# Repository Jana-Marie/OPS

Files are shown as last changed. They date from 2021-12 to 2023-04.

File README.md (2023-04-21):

# OPS

OPS is a matchbox sized 65W CC/CV lab power supply. It is controlled by SCPI and powered by USB-PD.

**Please Note that this project is not yet fully tested.**

<table>
  <tbody>
    <tr>
      <td colspan="2">
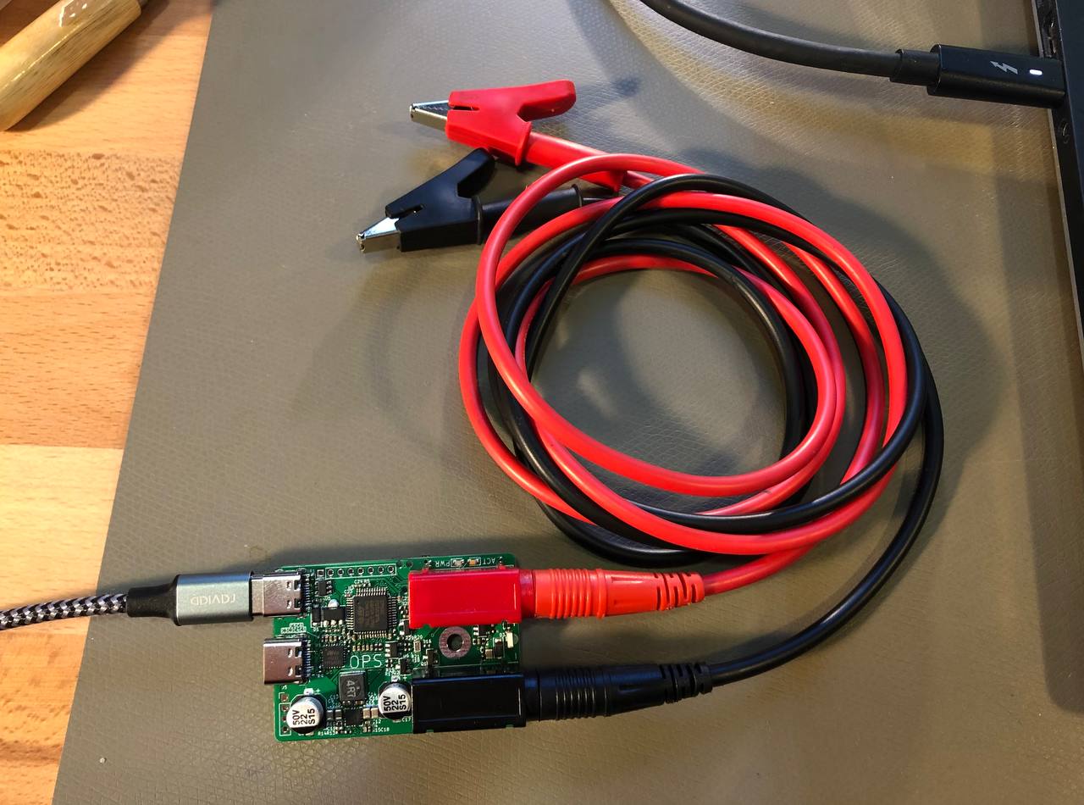
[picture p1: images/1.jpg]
        
      </td>
    </tr>
    <tr>
      <td>
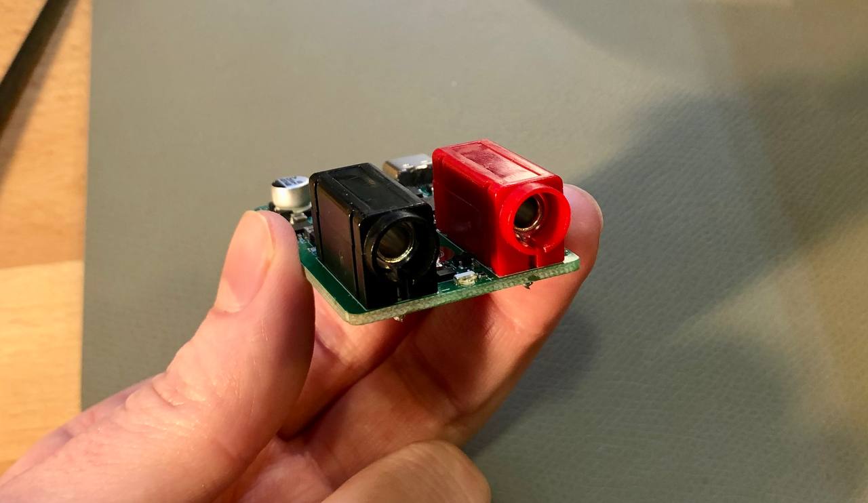
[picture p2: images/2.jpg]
        
      </td>
      <td>
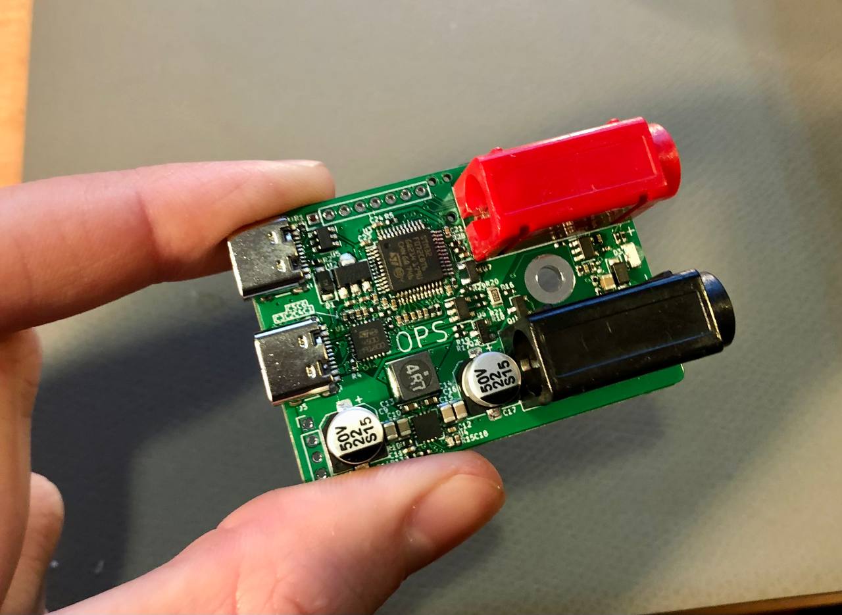
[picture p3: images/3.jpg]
        
      </td>
    </tr>
    <tr>
      <td colspan="2">
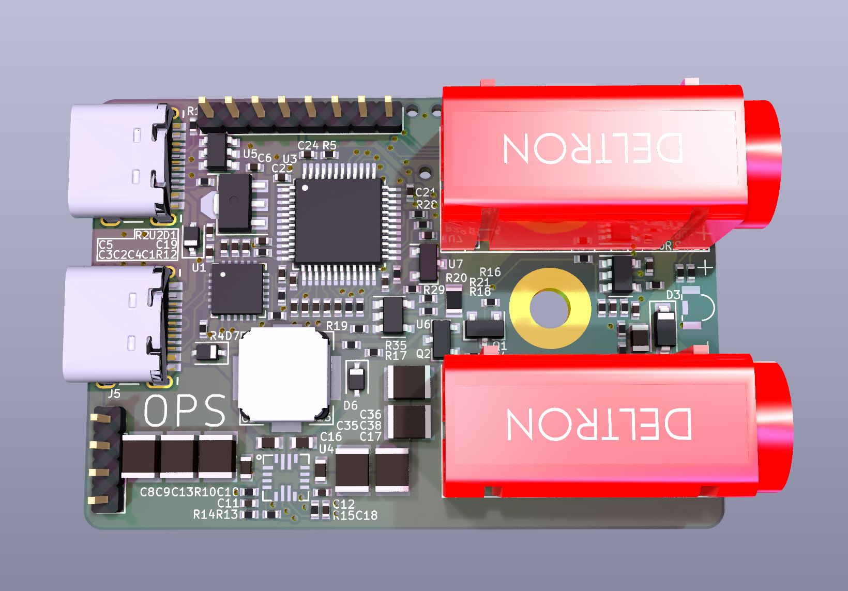
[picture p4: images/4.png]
        
      </td>
    </tr>
    <tr>
      <td>
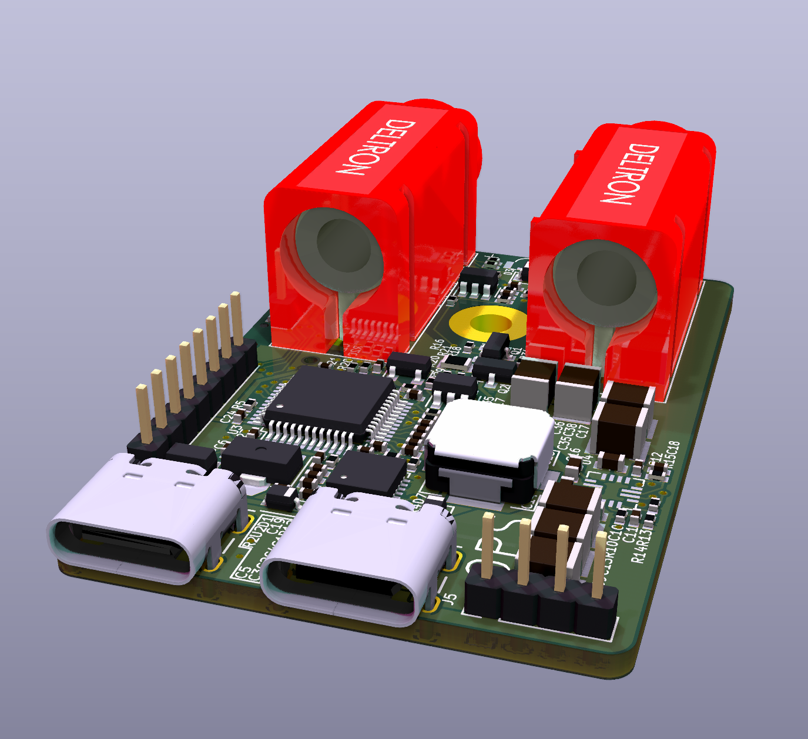
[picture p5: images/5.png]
        
      </td>
      <td>
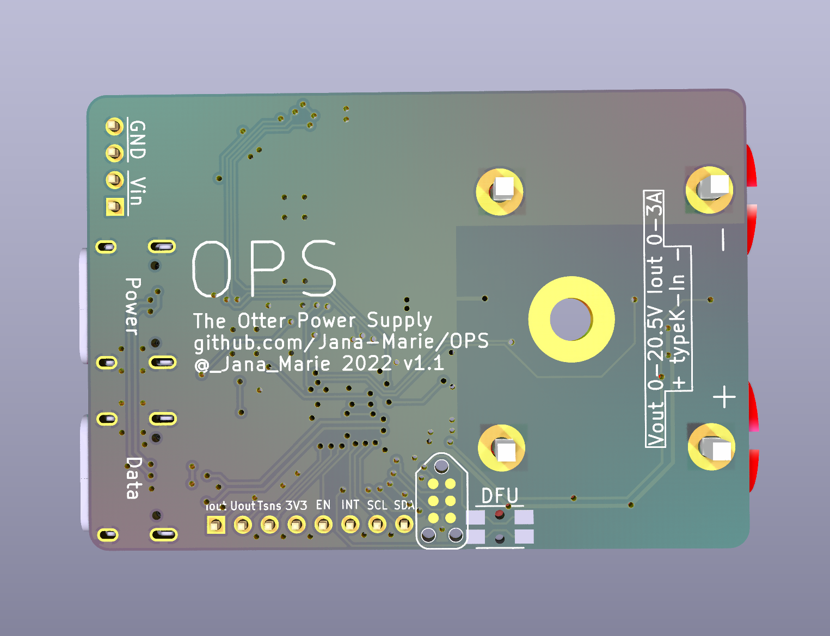
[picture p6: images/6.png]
        
      </td>
    </tr>
  </tbody>
</table>

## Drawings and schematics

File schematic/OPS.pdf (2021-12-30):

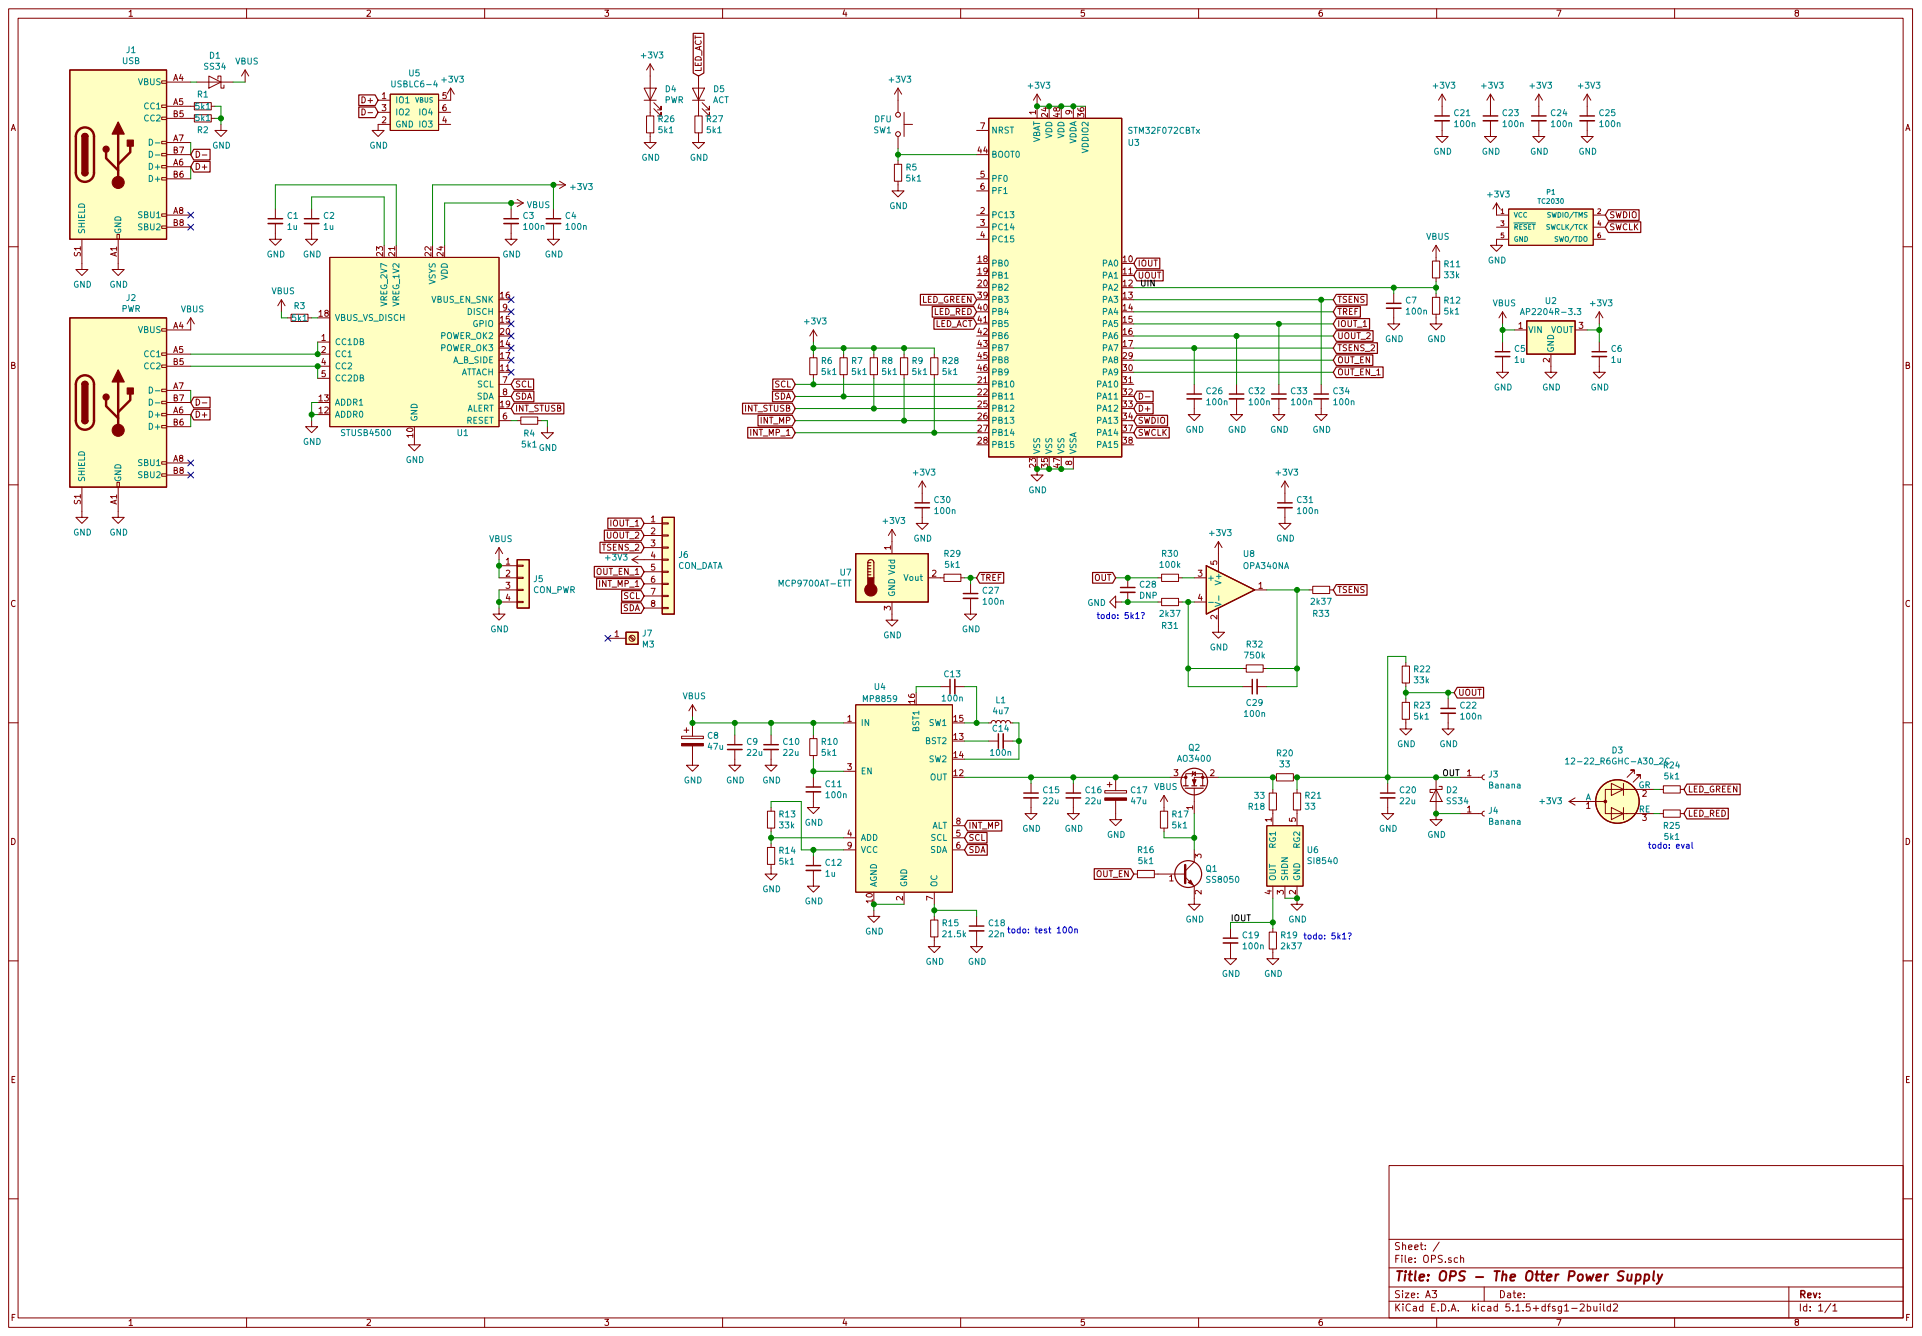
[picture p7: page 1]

1 PA0 10 PA1 11 PA2 12 PA3 13 PA4 14 PA5 15 PA6 16 PA7 17 PB0 18 PB1 19 PC13 2 PB2 20 PB10 21 PB11 22 VSS 23 VDD 24 PB12 25 PB13 26 PB14 27 PB15 28 PA8 29 PC14 3 PA9 30 PA10 31 PA11 32 PA12 33 PA13 34 VSS 35 VDDIO2 36 PA14 37 PA15 38 PB3 39 PC15 4 PB4 40 PB5 41 PB6 42 PB7 43 BOOT0 44 PB8 45 PB9 46 VSS 47 VDD 48 PF0 5 PF1 6 NRST 7 VSSA

2 EN 3 ADD 4 SCL 5 SDA 6 OC

File: OPS.sch Sheet: / GND

Id: 1/1 Title: OPS - The Otter Power Supply

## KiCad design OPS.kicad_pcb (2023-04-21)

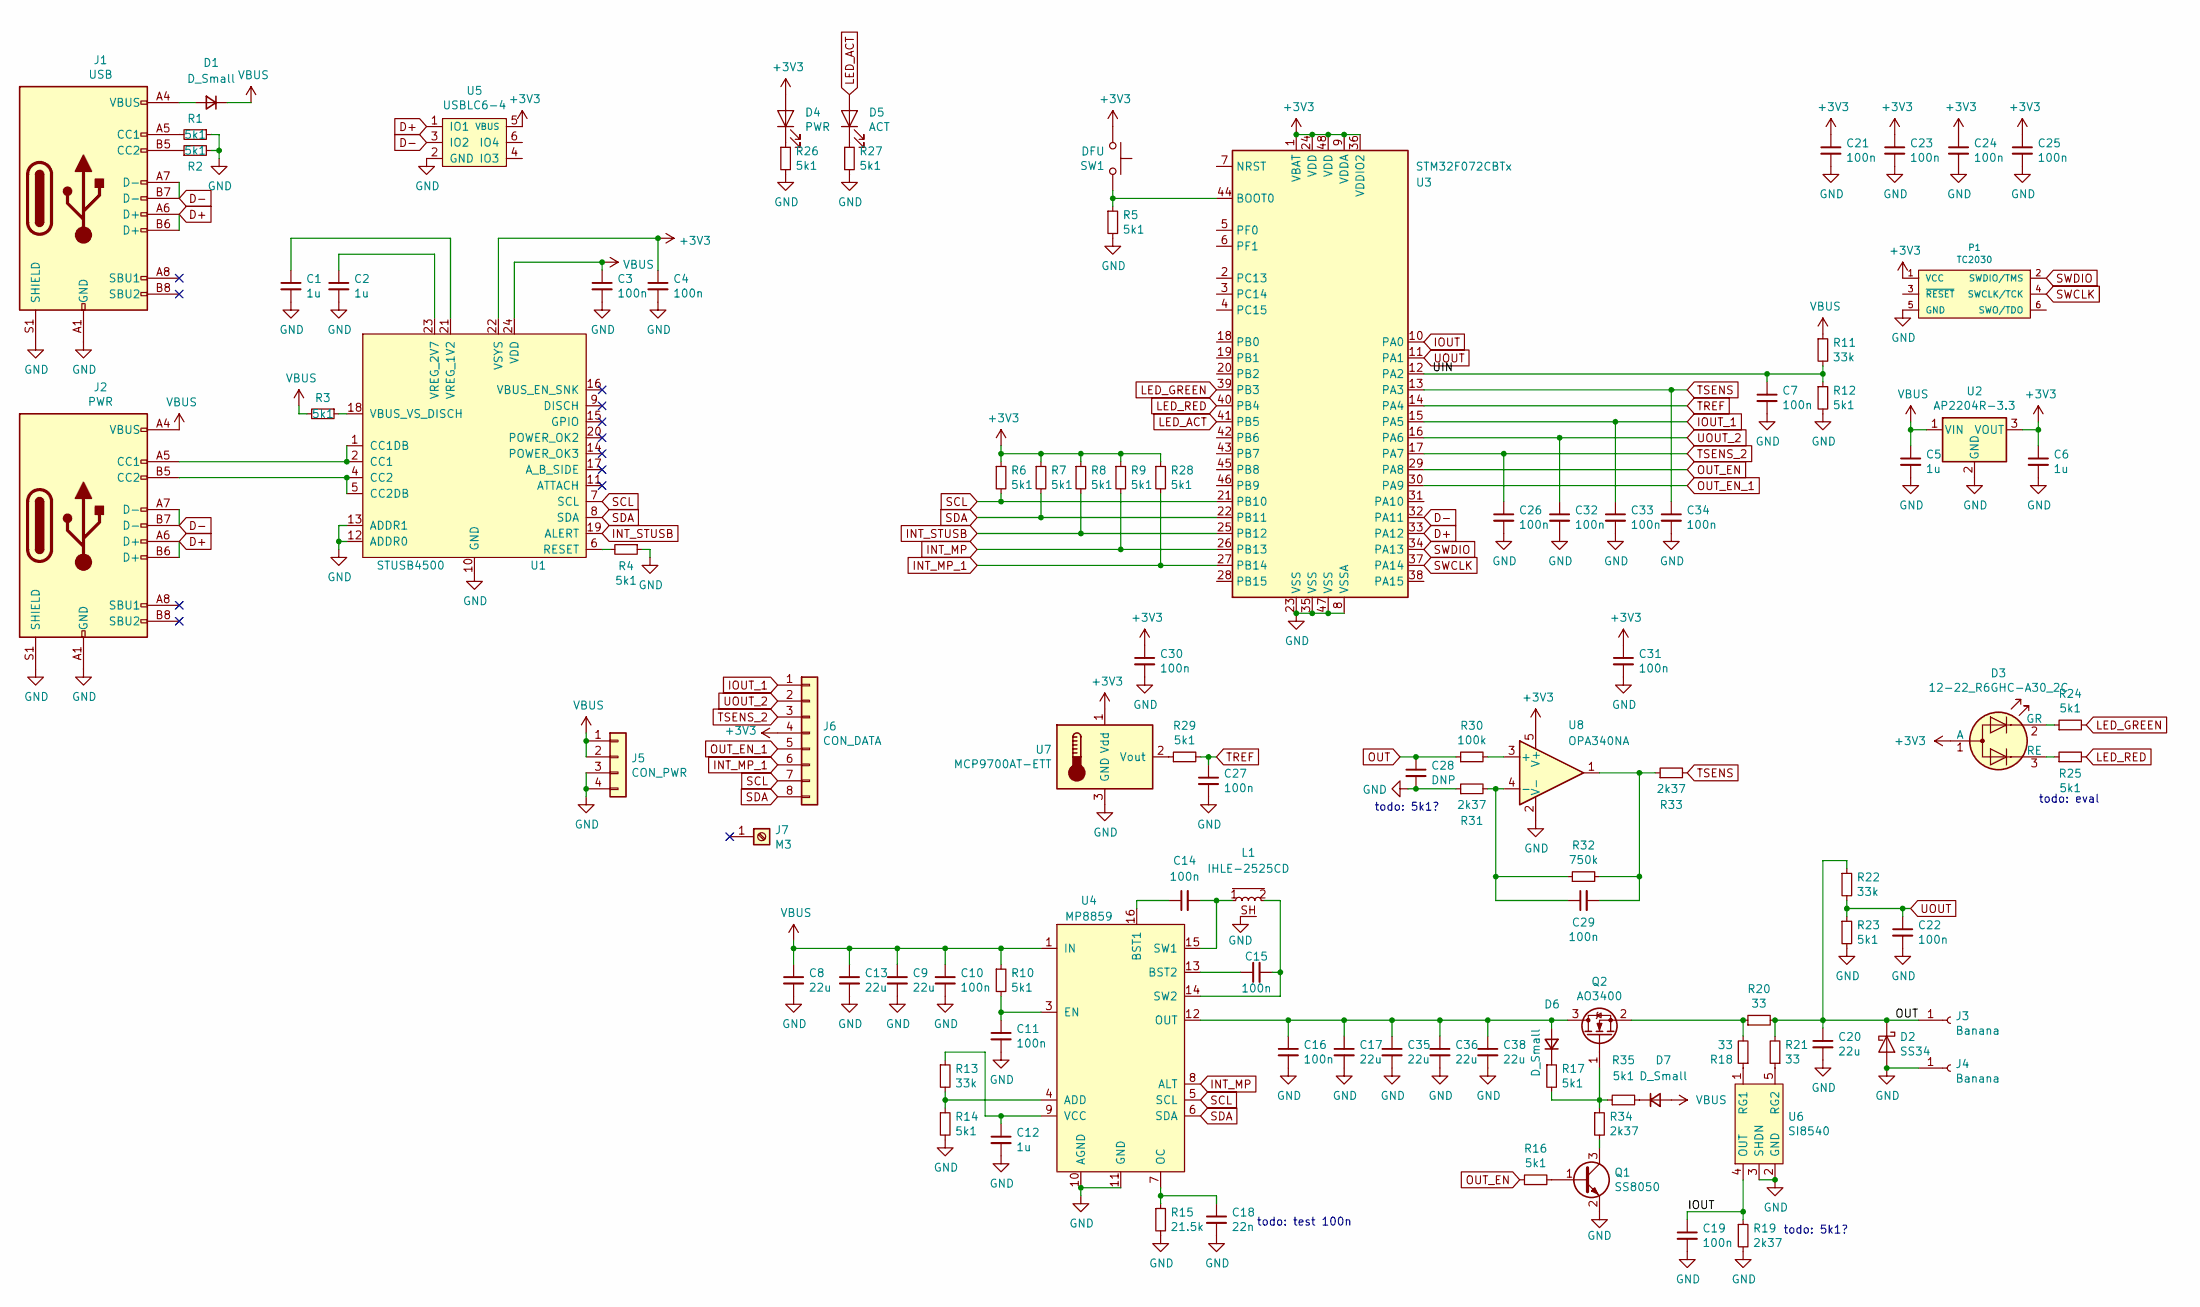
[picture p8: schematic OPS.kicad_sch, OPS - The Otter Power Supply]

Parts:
C1, C2, C5, C6, C12: 1u; C_0402
C3, C4, C7, C11, C19, C21, C22, C23, C24, C25, C26, C27, C29, C30, C31, C32, C33, C34: 100n; C_0402
C8, C9, C13, C17, C35, C36, C38: 22u; C_1210
C10, C14, C15, C16: 100n; C_0603
C18: 22n; C_0402
C20: 22u; C_0805
C28: DNP; C_0402
D1, D6, D7: D_Small; D_SOD-323
D2: SS34; D_SOD-123
D3: 12-22_R6GHC-A30_2C; R6GHC-A30
D4: PWR; LED_0603_1608Metric
D5: ACT; LED_0603_1608Metric
J1: USB; USB-C 16Pin
J2: PWR; USB-C 16Pin
J3, J4: Banana; banana-jack
J5: CON_PWR; PinHeader_1x04_P2.00mm_Vertical
J6: CON_DATA; PinHeader_1x08_P2.00mm_Vertical
J7: M3; MountingHole_3.2mm_M3_Pad
L1: IHLE-2525CD
P1: TC2030
Q1: SS8050; SOT-23
Q2: AO3400; SOT-23
R1, R2, R3, R4, R5, R6, R7, R8, R9, R10, R12, R14, R16, R17, R23, R24, R25, R26, R27, R28, R29, R35: 5k1; R_0402
R11, R13, R22: 33k; R_0402
R15: 21.5k; R_0402
R18, R21: 33; R_0402
R19, R31, R33, R34: 2k37; R_0402
R20: 33; R_0805
R30: 100k; R_0402
R32: 750k; R_0402
SW1: DFU; SW_SPST_EVQP7C
U1: STUSB4500; QFN-24-1EP_4x4mm_P0.5mm_EP2.7x2.7mm
U2: AP2204R-3.3; SOT-89-3
U3: STM32F072CBTx; LQFP-48_7x7mm_P0.5mm
U4: MP8859
U5: USBLC6-4; SOT-23-6
U6: SI8540; SOT-23-5
U7: MCP9700AT-ETT; SOT-23
U8: OPA340NA; SOT-23-5

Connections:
+3V3: C4.1, C6.1, C21.1, C23.1, C24.1, C25.1, C30.1, C31.1, D3.1 (A), D4.2 (A), J6.4, P1.1 (VCC), R6.1, R7.1, R8.1, R9.1, R28.1, SW1.1, U1.22 (VSYS), U2.3 (VOUT), U3.1 (VBAT), U3.9 (VDDA), U3.24 (VDD), U3.36 (VDDIO2), U3.48 (VDD), U5.5 (VBUS), U7.1 (Vdd), U8.5 (V+)
/UIN: C7.1, R11.2, R12.1, U3.12 (PA2)
D+: J1.A6 (D+), J1.B6 (D+), J2.A6 (D+), J2.B6 (D+), U3.33 (PA12), U5.1 (IO1)
D-: J1.A7 (D-), J1.B7 (D-), J2.A7 (D-), J2.B7 (D-), U3.32 (PA11), U5.3 (IO2)
GND: C1.2, C2.2, C3.2, C4.2, C5.2, C6.2, C7.2, C8.2, C9.2, C10.2, C11.2, C12.2, C13.2, C16.2, C17.2, C18.2, C19.2, C20.2, C21.2, C22.2, C23.2, C24.2, C25.2, C26.2, C27.2, C28.2, C30.2, C31.2, C32.2, C33.2, C34.2, C35.2, C36.2, C38.2, D2.2 (A), J1.A1 (GND), J1.A12 (GND), J1.B1 (GND), J1.B12 (GND), J1.S1 (SHIELD), J2.A1 (GND), J2.A12 (GND), J2.B1 (GND), J2.B12 (GND), J2.S1 (SHIELD), J4.1, J5.3, J5.4, L1.SH, P1.5 (GND), Q1.2 (E), R1.1, R2.2, R4.1, R5.2, R12.2, R14.2, R15.2, R19.2, R23.2, R26.2, R27.2, R31.1, U1.10 (GND), U1.12 (ADDR0), U1.13 (ADDR1), U1.25 (GND), U2.2 (GND), U3.8 (VSSA), U3.23 (VSS), U3.35 (VSS), U3.47 (VSS), U4.2 (GND), U4.10 (AGND), U4.11 (GND), U5.2 (GND), U6.2 (GND), U6.3 (SHDN), U7.3 (GND), U8.2 (V-)
INT_MP: R9.2, U3.26 (PB13), U4.8 (ALT)
INT_MP_1: J6.6, R28.2, U3.27 (PB14)
INT_STUSB: R8.2, U1.19 (ALERT), U3.25 (PB12)
IOUT: C19.1, R19.1, U3.10 (PA0), U6.4 (OUT)
IOUT_1: C33.1, J6.1, U3.15 (PA5)
LED_ACT: D5.2 (A), U3.41 (PB5)
LED_GREEN: R24.2, U3.39 (PB3)
LED_RED: R25.2, U3.40 (PB4)
unnamed: C1.1, U1.21 (VREG_1V2)
unnamed: C2.1, U1.23 (VREG_2V7)
unnamed: C11.1, R10.2, U4.3 (EN)
unnamed: C12.1, R13.1, U4.9 (VCC)
unnamed: C14.1, U4.16 (BST1)
unnamed: C14.2, L1.1, U4.15 (SW1)
unnamed: C15.1, U4.13 (BST2)
unnamed: C15.2, L1.2, U4.14 (SW2)
unnamed: C16.1, C17.1, C35.1, C36.1, C38.1, D6.2 (A), Q2.3 (D), U4.12 (OUT)
unnamed: C18.1, R15.1, U4.7 (OC)
unnamed: C29.1, R31.2, R32.1, U8.4 (-)
unnamed: C29.2, R32.2, R33.1, U8.1
unnamed: D1.2 (A), J1.A4 (VBUS), J1.A9 (VBUS), J1.B4 (VBUS), J1.B9 (VBUS)
unnamed: D3.2 (GR), R24.1
unnamed: D3.3 (RE), R25.1
unnamed: D4.1 (K), R26.1
unnamed: D5.1 (K), R27.1
unnamed: D6.1 (K), R17.1
unnamed: D7.1 (K), R35.2
unnamed: J1.A5 (CC1), R1.2
unnamed: J1.B5 (CC2), R2.1
unnamed: J2.A5 (CC1), U1.1 (CC1DB), U1.2 (CC1)
unnamed: J2.B5 (CC2), U1.4 (CC2), U1.5 (CC2DB)
unnamed: Q1.1 (B), R16.2
unnamed: Q1.3 (C), R34.2
unnamed: Q2.1 (G), R17.2, R34.1, R35.1
unnamed: Q2.2 (S), R18.2, R20.1
unnamed: R3.1, U1.18 (VBUS_VS_DISCH)
unnamed: R4.2, U1.6 (RESET)
unnamed: R5.1, SW1.2, U3.44 (BOOT0)
unnamed: R13.2, R14.1, U4.4 (ADD)
unnamed: R18.1, U6.1 (RG1)
unnamed: R21.1, U6.5 (RG2)
unnamed: R29.1, U7.2 (Vout)
unnamed: R30.2, U8.3 (+)
OUT: C20.1, C28.1, D2.1 (K), J3.1, R20.2, R21.2, R22.1, R30.1
OUT_EN: R16.1, U3.29 (PA8)
OUT_EN_1: J6.5, U3.30 (PA9)
SCL: J6.7, R6.2, U1.7 (SCL), U3.21 (PB10), U4.5 (SCL)
SDA: J6.8, R7.2, U1.8 (SDA), U3.22 (PB11), U4.6 (SDA)
SWCLK: P1.4 (SWCLK/TCK), U3.37 (PA14)
SWDIO: P1.2 (SWDIO/TMS), U3.34 (PA13)
TREF: C27.1, R29.2, U3.14 (PA4)
TSENS: C34.1, R33.2, U3.13 (PA3)
TSENS_2: C26.1, J6.3, U3.17 (PA7)
UOUT: C22.1, R22.2, R23.1, U3.11 (PA1)
UOUT_2: C32.1, J6.2, U3.16 (PA6)
VBUS: C3.1, C5.1, C8.1, C9.1, C10.1, C13.1, D1.1 (K), D7.2 (A), J2.A4 (VBUS), J2.A9 (VBUS), J2.B4 (VBUS), J2.B9 (VBUS), J5.1, J5.2, R3.2, R10.1, R11.1, U1.24 (VDD), U2.1 (VIN), U4.1 (IN)

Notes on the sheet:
todo: 5k1?
todo: eval
todo: test 100n

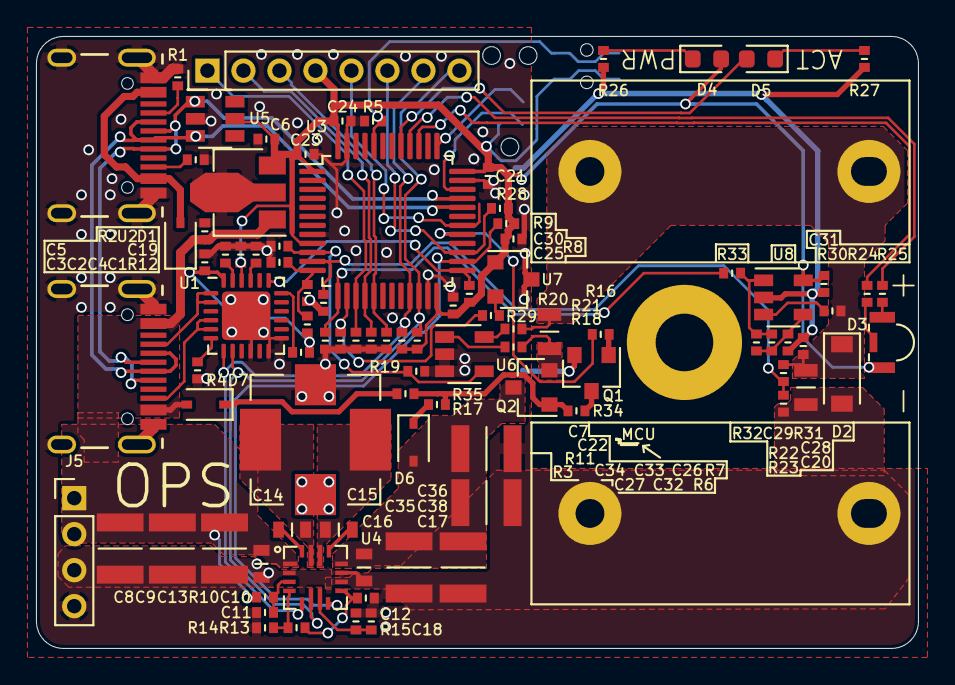
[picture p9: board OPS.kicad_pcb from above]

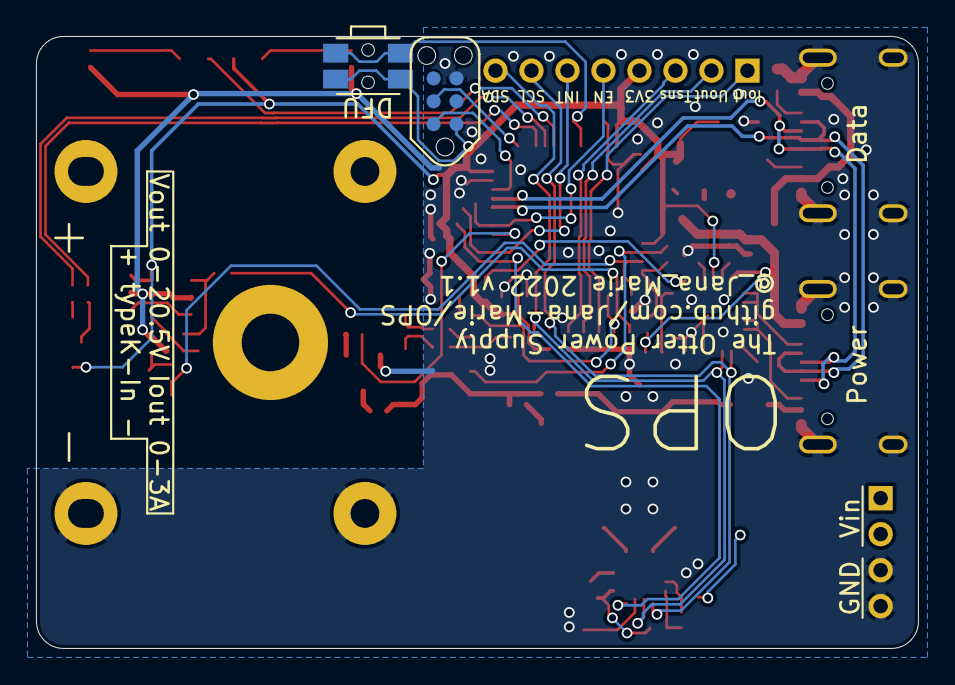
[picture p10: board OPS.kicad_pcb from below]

Board: 2 copper layers, 49.0 x 34.0 mm, 99 parts (2 on the bottom side), 61 nets.

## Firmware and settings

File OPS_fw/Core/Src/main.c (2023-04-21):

#include "main.h"
#include "MP8862.h"
//#include "usbd_cdc_if.h"
//#include "usb_device.h"
//#include "scpi/scpi.h"
//#include "scpi-def.h"

ADC_HandleTypeDef hadc;
DMA_HandleTypeDef hdma_adc;

I2C_HandleTypeDef hi2c2;
DMA_HandleTypeDef hdma_i2c2_rx;
DMA_HandleTypeDef hdma_i2c2_tx;

TIM_HandleTypeDef htim1;
TIM_HandleTypeDef htim2;

void SystemClock_Config(void);
static void MX_GPIO_Init(void);
static void MX_I2C2_Init(void);
static void MX_DMA_Init(void);
static void MX_ADC_Init(void);
static void MX_TIM1_Init(void);
static void MX_TIM2_Init(void);

static uint32_t adc[8];
struct MP8862_t MP8862;
uint8_t adc_ready_flag = 0;

struct ops ops;
uint8_t addr[128];    

//extern uint8_t UserRxBufferFS[APP_RX_DATA_SIZE];
//extern uint8_t UserTxBufferFS[APP_TX_DATA_SIZE];
//uint8_t is_new_data_ready;
//uint16_t new_data_length;

//uint16_t sine[60] = {0x251c,0x28fd,0x2cd3,0x3094,0x3434,0x37aa,0x3aec,0x3df1,0x40b0,0x4322,0x453f,0x4703,0x4867,0x4968,0x4a04,0x4a38,0x4a04,0x4968,0x4867,0x4703,0x453f,0x4322,0x40b0,0x3df1,0x3aec,0x37aa,0x3434,0x3094,0x2cd3,0x28fd,0x251c,0x213b,0x1d65,0x19a4,0x1604,0x128e,0xf4c,0xc47,0x988,0x716,0x4f9,0x335,0x1d1,0xd0,0x34,0x0,0x34,0xd0,0x1d1,0x335,0x4f9,0x716,0x988,0xc47,0xf4c,0x128e,0x1604,0x19a4,0x1d65,0x213b};
uint16_t sine[60] = {4500,4970,5436,5891,6330,6750,7145,7511,7844,8141,8397,8611,8780,8902,8975,9000,8975,8902,8780,8611,8397,8141,7844,7511,7145,6750,6330,5891,5436,4970,4500,4030,3564,3109,2670,2250,1855,1489,1156,859,603,389,220,98,25,0,25,98,220,389,603,859,1156,1489,1855,2250,2670,3109,3564,4030};


uint8_t reg1,reg2,go,stat,vlo,vhi,ir;

int main(void)
{
  HAL_Init();
  SystemClock_Config();

  MX_GPIO_Init();
  MX_I2C2_Init();
  MX_DMA_Init();
  MX_ADC_Init();
  MX_TIM1_Init();
  MX_TIM2_Init();
  //MX_USB_DEVICE_Init();

  HAL_GPIO_WritePin(GPIOB, LED_GREEN_Pin, 1);
  HAL_GPIO_WritePin(GPIOB, LED_RED_Pin, 1);

  HAL_Delay(100);


  MP8862_init(&MP8862, &hi2c2, MP8862_ADDR_0x69);
  MP8862_setVoltageSetpoint_mV(&MP8862, 400);
  MP8862_setCurrentLimit_mA(&MP8862, 6000);
  HAL_Delay(50);
  uint8_t isReady = MP8862_setEnable(&MP8862, 1);

  if(isReady){
    HAL_GPIO_WritePin(GPIOB, LED_GREEN_Pin, 0);
  } else {
    HAL_GPIO_WritePin(GPIOB, LED_RED_Pin, 0);
    HAL_GPIO_WritePin(GPIOB, LED_GREEN_Pin, 0);
  }

  HAL_ADC_Start_DMA(&hadc, adc, 8);
  HAL_TIM_Base_Start_IT(&htim2);

  //SCPI_Init(&scpi_context,
  //  scpi_commands,
  //  &scpi_interface,
  //  scpi_units_def,
  //  SCPI_IDN1, SCPI_IDN2, SCPI_IDN3, SCPI_IDN4,
  //  scpi_input_buffer, SCPI_INPUT_BUFFER_LENGTH,
  //  scpi_error_queue_data, SCPI_ERROR_QUEUE_SIZE);

  while (1)
  {

    //HAL_Delay(25);
    //MP8862_read(&MP8862, MP8862_REG_CTL1 , &reg1, 1 );
    //MP8862_read(&MP8862, MP8862_REG_CTL2 , &reg2, 1 );
    //MP8862_read(&MP8862, MP8862_REG_VOUT_GO , &go, 1 );
    //MP8862_read(&MP8862, MP8862_REG_STATUS , &stat, 1 );
    //MP8862_read(&MP8862, MP8862_REG_VOUT_L , &vlo, 1 );
    //MP8862_read(&MP8862, MP8862_REG_VOUT_H , &vhi, 1 );
    //MP8862_readCurrentLimit_mA(&MP8862, &ir);
    //MP8862_read(&MP8862, MP8862_REG_INTERRUPT , &ir, 1 );
    //MP8862_write(&MP8862, MP8862_REG_INTERRUPT , 0xff, 1 );
    //char _err[150] = {0};
    //sprintf(_err, "DBG\tR1=%d\tR2=%d\tgo=%d\tstat=%d\tlo=%d\thi=%d\tir=%d\n\r", reg1,reg2,go,stat,vlo,vhi,ir);
    //CDC_Transmit_FS(_err, 150);

    // Sine-Ramp for testing
    for(uint8_t i = 0; i < 60; i++){
      MP8862_setVoltageSetpoint_mV(&MP8862, sine[i]);
      HAL_GPIO_TogglePin(GPIOB, LED_ACT_Pin);
      HAL_Delay(25);
    }

    if (adc_ready_flag) {
      ops.vbus = adc[2]/4095.0*3.3*7.471;
      ops.vout = adc[1]/4095.0*3.3*7.471;
      ops.iout = (adc[0]/4095.0*3.3*1.659)/(0.01*(2370/33));
      ops.tref = (((adc[4]/4095.0)*3.3)-0.5)/0.01;
      ops.tc   = ((adc[3]-120)*92)/1000+ops.tref;

    }
      for (uint8_t i=1; i<=127; i++) {
    HAL_StatusTypeDef result;
    result = HAL_I2C_IsDeviceReady(&hi2c2, (uint16_t)(i<<1), 4, 4);
    if (result == HAL_OK) {
      // If in this scope, i == device on bus, do whatever you want or need
      addr[i] = 1;
      //print(i);
    }
    HAL_Delay(1);
  }


    //if (is_new_data_ready) {
    //  HAL_GPIO_WritePin(GPIOB, LED_ACT_Pin, 1);
    //  CDC_Transmit_FS(UserRxBufferFS, new_data_length);
    //  SCPI_Input(&scpi_context, UserRxBufferFS, new_data_length);
    //  is_new_data_ready = 0;
    //}
  }
}

void SystemClock_Config(void)
{
  RCC_OscInitTypeDef RCC_OscInitStruct = {0};
  RCC_ClkInitTypeDef RCC_ClkInitStruct = {0};
  RCC_PeriphCLKInitTypeDef PeriphClkInit = {0};

  RCC_OscInitStruct.OscillatorType = RCC_OSCILLATORTYPE_HSI14|RCC_OSCILLATORTYPE_HSI48;
  RCC_OscInitStruct.HSI48State = RCC_HSI48_ON;
  RCC_OscInitStruct.HSI14State = RCC_HSI14_ON;
  RCC_OscInitStruct.HSI14CalibrationValue = 16;
  RCC_OscInitStruct.PLL.PLLState = RCC_PLL_NONE;
  HAL_RCC_OscConfig(&RCC_OscInitStruct);

  RCC_ClkInitStruct.ClockType = RCC_CLOCKTYPE_HCLK|RCC_CLOCKTYPE_SYSCLK
                              |RCC_CLOCKTYPE_PCLK1;
  RCC_ClkInitStruct.SYSCLKSource = RCC_SYSCLKSOURCE_HSI48;
  RCC_ClkInitStruct.AHBCLKDivider = RCC_SYSCLK_DIV1;
  RCC_ClkInitStruct.APB1CLKDivider = RCC_HCLK_DIV1;
  HAL_RCC_ClockConfig(&RCC_ClkInitStruct, FLASH_LATENCY_1);

  PeriphClkInit.PeriphClockSelection = RCC_PERIPHCLK_USB;
  PeriphClkInit.UsbClockSelection = RCC_USBCLKSOURCE_HSI48;
  HAL_RCCEx_PeriphCLKConfig(&PeriphClkInit);
}

static void MX_ADC_Init(void)
{
  ADC_ChannelConfTypeDef sConfig = {0};

  hadc.Instance = ADC1;
  hadc.Init.ClockPrescaler = ADC_CLOCK_ASYNC_DIV1;
  hadc.Init.Resolution = ADC_RESOLUTION_12B;
  hadc.Init.DataAlign = ADC_DATAALIGN_RIGHT;
  hadc.Init.ScanConvMode = ADC_SCAN_DIRECTION_FORWARD;
  hadc.Init.EOCSelection = ADC_EOC_SEQ_CONV;
  hadc.Init.LowPowerAutoWait = DISABLE;
  hadc.Init.LowPowerAutoPowerOff = DISABLE;
  hadc.Init.ContinuousConvMode = DISABLE;
  hadc.Init.DiscontinuousConvMode = DISABLE;
  hadc.Init.ExternalTrigConv = ADC_EXTERNALTRIGCONV_T2_TRGO;
  hadc.Init.ExternalTrigConvEdge = ADC_EXTERNALTRIGCONVEDGE_RISING;
  hadc.Init.DMAContinuousRequests = ENABLE;
  hadc.Init.Overrun = ADC_OVR_DATA_PRESERVED;
  HAL_ADC_Init(&hadc);

  sConfig.Channel = ADC_CHANNEL_0;
  sConfig.Rank = ADC_RANK_CHANNEL_NUMBER;
  sConfig.SamplingTime = ADC_SAMPLETIME_55CYCLES_5;
  HAL_ADC_ConfigChannel(&hadc, &sConfig);

  sConfig.Channel = ADC_CHANNEL_1;
  HAL_ADC_ConfigChannel(&hadc, &sConfig);

  sConfig.Channel = ADC_CHANNEL_2;
  HAL_ADC_ConfigChannel(&hadc, &sConfig);

  sConfig.Channel = ADC_CHANNEL_3;
  HAL_ADC_ConfigChannel(&hadc, &sConfig);

  sConfig.Channel = ADC_CHANNEL_4;
  HAL_ADC_ConfigChannel(&hadc, &sConfig);

  sConfig.Channel = ADC_CHANNEL_5;
  HAL_ADC_ConfigChannel(&hadc, &sConfig);

  sConfig.Channel = ADC_CHANNEL_6;
  HAL_ADC_ConfigChannel(&hadc, &sConfig);

  sConfig.Channel = ADC_CHANNEL_7;
  HAL_ADC_ConfigChannel(&hadc, &sConfig);
}

static void MX_I2C2_Init(void)
{
  hi2c2.Instance = I2C2;
  hi2c2.Init.Timing = 0x2010091A;
  hi2c2.Init.OwnAddress1 = 0;
  hi2c2.Init.AddressingMode = I2C_ADDRESSINGMODE_7BIT;
  hi2c2.Init.DualAddressMode = I2C_DUALADDRESS_DISABLE;
  hi2c2.Init.OwnAddress2 = 0;
  hi2c2.Init.OwnAddress2Masks = I2C_OA2_NOMASK;
  hi2c2.Init.GeneralCallMode = I2C_GENERALCALL_DISABLE;
  hi2c2.Init.NoStretchMode = I2C_NOSTRETCH_DISABLE;
  HAL_I2C_Init(&hi2c2);
  HAL_I2CEx_ConfigAnalogFilter(&hi2c2, I2C_ANALOGFILTER_ENABLE);
  HAL_I2CEx_ConfigDigitalFilter(&hi2c2, 0);
}

static void MX_TIM1_Init(void)
{
  TIM_ClockConfigTypeDef sClockSourceConfig = {0};
  TIM_MasterConfigTypeDef sMasterConfig = {0};

  htim1.Instance = TIM1;
  htim1.Init.Prescaler = 16;
  htim1.Init.CounterMode = TIM_COUNTERMODE_UP;
  htim1.Init.Period = 1024;
  htim1.Init.ClockDivision = TIM_CLOCKDIVISION_DIV1;
  htim1.Init.RepetitionCounter = 0;
  htim1.Init.AutoReloadPreload = TIM_AUTORELOAD_PRELOAD_DISABLE;
  HAL_TIM_Base_Init(&htim1);

  sClockSourceConfig.ClockSource = TIM_CLOCKSOURCE_INTERNAL;
  HAL_TIM_ConfigClockSource(&htim1, &sClockSourceConfig);

  sMasterConfig.MasterOutputTrigger = TIM_TRGO_RESET;
  sMasterConfig.MasterSlaveMode = TIM_MASTERSLAVEMODE_DISABLE;
  HAL_TIMEx_MasterConfigSynchronization(&htim1, &sMasterConfig);
}

static void MX_TIM2_Init(void)
{
  TIM_ClockConfigTypeDef sClockSourceConfig = {0};
  TIM_MasterConfigTypeDef sMasterConfig = {0};

  htim2.Instance = TIM2;
  htim2.Init.Prescaler = 9999;
  htim2.Init.CounterMode = TIM_COUNTERMODE_UP;
  htim2.Init.Period = 479;
  htim2.Init.ClockDivision = TIM_CLOCKDIVISION_DIV1;
  htim2.Init.AutoReloadPreload = TIM_AUTORELOAD_PRELOAD_ENABLE;
  HAL_TIM_Base_Init(&htim2);

  sClockSourceConfig.ClockSource = TIM_CLOCKSOURCE_INTERNAL;
  HAL_TIM_ConfigClockSource(&htim2, &sClockSourceConfig);

  sMasterConfig.MasterOutputTrigger = TIM_TRGO_UPDATE;
  sMasterConfig.MasterSlaveMode = TIM_MASTERSLAVEMODE_DISABLE;
  HAL_TIMEx_MasterConfigSynchronization(&htim2, &sMasterConfig);
}

static void MX_DMA_Init(void)
{
  __HAL_RCC_DMA1_CLK_ENABLE();

  HAL_NVIC_SetPriority(DMA1_Channel1_IRQn, 0, 0);
  HAL_NVIC_EnableIRQ(DMA1_Channel1_IRQn);
  HAL_NVIC_SetPriority(DMA1_Channel4_5_6_7_IRQn, 0, 0);
  HAL_NVIC_EnableIRQ(DMA1_Channel4_5_6_7_IRQn);
}

static void MX_GPIO_Init(void)
{
  GPIO_InitTypeDef GPIO_InitStruct = {0};

  __HAL_RCC_GPIOA_CLK_ENABLE();
  __HAL_RCC_GPIOB_CLK_ENABLE();

  HAL_GPIO_WritePin(GPIOA, OUT_EN_1_Pin|OUT_EN_2_Pin, GPIO_PIN_RESET);

  HAL_GPIO_WritePin(GPIOB, LED_GREEN_Pin|LED_RED_Pin|LED_ACT_Pin, GPIO_PIN_RESET);

  GPIO_InitStruct.Pin = INT_STUSB_Pin|INT_MP_1_Pin|INT_MP_2_Pin;
  GPIO_InitStruct.Mode = GPIO_MODE_IT_RISING;
  GPIO_InitStruct.Pull = GPIO_NOPULL;
  HAL_GPIO_Init(GPIOB, &GPIO_InitStruct);

  GPIO_InitStruct.Pin = OUT_EN_1_Pin|OUT_EN_2_Pin;
  GPIO_InitStruct.Mode = GPIO_MODE_OUTPUT_PP;
  GPIO_InitStruct.Pull = GPIO_NOPULL;
  GPIO_InitStruct.Speed = GPIO_SPEED_FREQ_LOW;
  HAL_GPIO_Init(GPIOA, &GPIO_InitStruct);

  GPIO_InitStruct.Pin = LED_GREEN_Pin|LED_RED_Pin|LED_ACT_Pin;
  GPIO_InitStruct.Mode = GPIO_MODE_OUTPUT_PP;
  GPIO_InitStruct.Pull = GPIO_NOPULL;
  GPIO_InitStruct.Speed = GPIO_SPEED_FREQ_LOW;
  HAL_GPIO_Init(GPIOB, &GPIO_InitStruct);
}

void Error_Handler(void)
{

  __disable_irq();
  while (1)
  {
  }
}

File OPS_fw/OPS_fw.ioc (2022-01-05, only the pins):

Mcu.UserName=STM32F072CBTx
PA0.Signal=ADC_IN0
PA1.Signal=ADC_IN1
PA11.Signal=USB_DM
PA12.Signal=USB_DP
PA13.Signal=SYS_SWDIO
PA14.Signal=SYS_SWCLK
PA2.Signal=ADC_IN2
PA3.Signal=ADC_IN3
PA4.Signal=ADC_IN4
PA5.Signal=ADC_IN5
PA6.Signal=ADC_IN6
PA7.Signal=ADC_IN7
PA8.GPIO_Label=OUT_EN_1
PA8.Signal=GPIO_Output
PA9.GPIO_Label=OUT_EN_2
PA9.Signal=GPIO_Output
PB10.Signal=I2C2_SCL
PB11.Signal=I2C2_SDA
PB12.GPIO_Label=INT_STUSB
PB12.Signal=GPXTI12
PB13.GPIO_Label=INT_MP_1
PB13.Signal=GPXTI13
PB14.GPIO_Label=INT_MP_2
PB14.Signal=GPXTI14
PB3.GPIO_Label=LED_GREEN
PB3.Signal=GPIO_Output
PB4.GPIO_Label=LED_RED
PB4.Signal=GPIO_Output
PB5.GPIO_Label=LED_ACT
PB5.Signal=GPIO_Output

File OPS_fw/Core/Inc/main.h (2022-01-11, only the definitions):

#define INT_STUSB_Pin GPIO_PIN_12
#define INT_STUSB_GPIO_Port GPIOB
#define INT_MP_1_Pin GPIO_PIN_13
#define INT_MP_1_GPIO_Port GPIOB
#define INT_MP_2_Pin GPIO_PIN_14
#define INT_MP_2_GPIO_Port GPIOB
#define OUT_EN_1_Pin GPIO_PIN_8
#define OUT_EN_1_GPIO_Port GPIOA
#define OUT_EN_2_Pin GPIO_PIN_9
#define OUT_EN_2_GPIO_Port GPIOA
#define LED_GREEN_Pin GPIO_PIN_3
#define LED_GREEN_GPIO_Port GPIOB
#define LED_RED_Pin GPIO_PIN_4
#define LED_RED_GPIO_Port GPIOB
#define LED_ACT_Pin GPIO_PIN_5
#define LED_ACT_GPIO_Port GPIOB

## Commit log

2021-04-19 started layout
    [OPS.kicad_pcb]
2021-04-26 routing 60%
    [OPS.kicad_pcb, OPS.sch]
2021-04-26 routing 99%
    [OPS.kicad_pcb, OPS.sch]
2021-12-30 updated silk
    [OPS-B_Cu.gbl, OPS-B_Mask.gbs, OPS-B_Paste.gbp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]
2022-01-05 updated to kicad 6
    [OPS.kicad_pcb, OPS.sch]
2022-01-05 initial fw commit, everything works, except the output mosfet, it needs to be removed from the design
2022-01-11 removed binaries
    [scpi.g]
2022-09-01 updated layout, exchanged PMIC caps and inductor
    [OPS.kicad_pcb]
2022-09-01 updated gerber
    [OPS-B_Cu.gbl, OPS-B_Mask.gbs, OPS-B_Paste.gbp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]
2022-09-01 removed bom
2023-04-21 remved gerber
    [OPS-B_Cu.gbl, OPS-B_Mask.gbs, OPS-B_Paste.gbp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]

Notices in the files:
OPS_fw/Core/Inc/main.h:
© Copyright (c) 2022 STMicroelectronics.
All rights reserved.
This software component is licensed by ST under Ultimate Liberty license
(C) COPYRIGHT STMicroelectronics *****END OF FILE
